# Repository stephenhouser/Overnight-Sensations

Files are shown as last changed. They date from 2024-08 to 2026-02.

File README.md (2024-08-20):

# Overnight Sensation Speakers

Overnight Sensations

This repository contains my build plans for [Paul Carmody](https://sites.google.com/site/undefinition/diy?authuser=0)'s **Overnight Sensations** speakers. It is intended to compliment Paul's designs, plans, and notes with manufacturable components. That is herein lie full CNC-able and PCB-producable components.

This currently includes details for the [original bookshelf speakers](https://sites.google.com/site/undefinition/bookshelf-speakers/diy-overnightsensations), the [floorstanding TMM's](https://sites.google.com/site/undefinition/floorstanding-speakers/overnightsensationtmm?authuser=0), and the [center speaker](https://sites.google.com/site/undefinition/home-theater-speakers/overnightsensationcenterchannelbipolewhatwhen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). I have future plans to include the [surround speakers](https://sites.google.com/site/undefinition/home-theater-speakers/overnightsensationcenterchannelbipolewhatwhen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).

This is a work in progress, bear with me as I build the speakers and add the components.

### A few notes on the designs

- Designed for 1/2" material. Using the 1/2" plans in all cases.
- Uses miter joints at the box corners, so can use already faced plywood.
- Uses painted MDF for the baffle. Could use faced plywood but the fillet on the outside edges would need to be removed.
- Does not use rabbet for back. Seems an overly complicated addition.

If you are using something else, it should be easily adapted.

## Bookshelf TM

No build files available.

I built these a few years ago and did not document things very well, save for a few photos and the build documents.

## Floorstanding TMM

TMM Glamor Shot

Includes:

- Cabinet Plans in FreeCAD
- Crossover PCB in KiCad with Gerbers for PCB manufacture
- 2"x3" port in FreeCAD for 3D printing

These are the most well developed plans as they are the most recent I've worked on.

NOTE: The version I have designed for uses the HiVi T20 tweeter and 1/2" thick wood for the cabinet. I've made some attempt at making the design general and adaptable, but you will likely have to tweak if you build the alternate version.

The cabinet design was reproduced from Paul's SketchUp screen capture into FreeCAD. The full FreeCAD files are in the [floorstanding[(floorstading)] directory. Here's a snapshot of the major dimensions. Perhaps enough to build from.

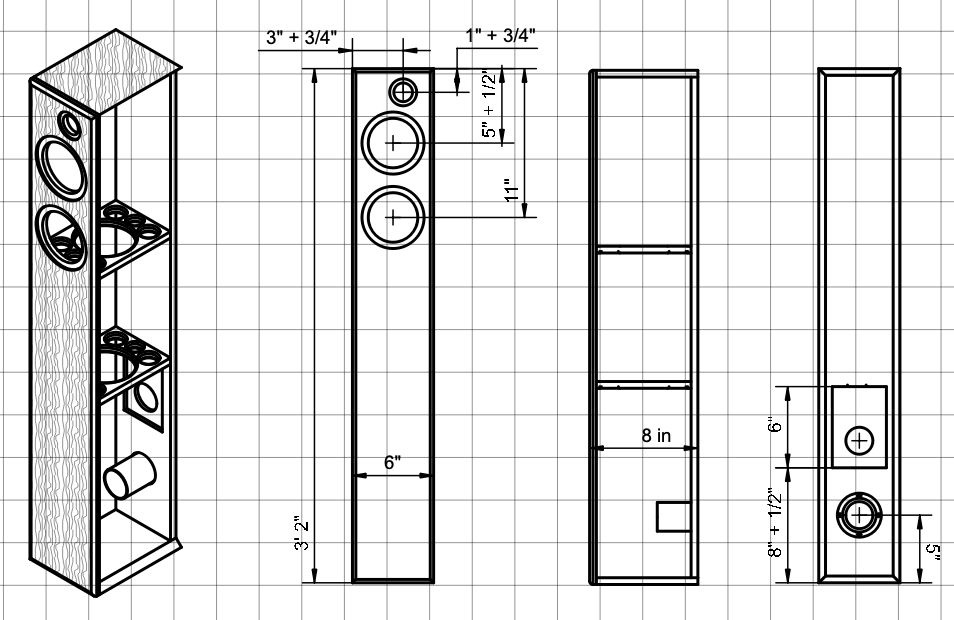
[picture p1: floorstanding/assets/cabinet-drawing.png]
Cabinet Drawing


My crossover PCB is for the HiVi T20 tweeter. You can use the same PCB, just substitute the different value components.

**NOTE**: I started working on alternate crossovers with thicker traces but stopped. See the notes below about **Power Handling**. I think the 3mm traces I have are "thick enough" for this configuration under normal use. It would be nice to have thicker traces (5-6mm), and 9.5mm spaced screw terminals. If I ever do make another PCB, I'll make those changes. Oh, I also forgot to put in additional holes for the wire ties on the 1.5 mH coil.

## Center MMTM

Cabinet Drawing

Next to be built!

## Surround

Yet to be built!

## Software Tools

I use the following software in the production of these. These are all open-source freely available products.

- [Inkscape](https://inkscape.org) for basic drawing and to generate SVG files for patterns.
- [KiCad](https://www.kicad.org) for schematic capture and PCB design.
- [FreeCAD](https://www.freecad.org) for cabinet design and CAM toolpath generation.
- [LibreOffice](https://www.libreoffice.org) for spreadsheets, bill of materials (BOM).

In the past I used the following software in parts of the process but am quickly moving away from them as I migrate to FreeCAD and other more open and interchangable software.

- [Carbide Create](https://carbide3d.com/carbidecreate/) / [Carbide Motion](https://carbide3d.com/carbidemotion/) for 2D CAD/CAM on Shapeoko 3
- [Autodesk Fusion 360](no link, autodesk keeps taking features away and I don't want to support that) for cabinet design and CAM toolpath generation

## Power Handling

To calculate what the power rating of the speaker is, and the appropriate trace width for the crossover boards.

- HiVi B4N is rated 25W RMS (50W max) at 8 Ohms, 60 - 4,000 Hz
- HiVi B3N is rated 10W RMS (30W max) at 8 Ohms, 80 - 12,000 Hz
- HiVi T20-8 is rated 15W RMS (no max specified) at 8 Ohms, 4,000 - 20,000 Hz

From some random source on the Internet:

    roughly 40-40-20 percentage for woofer, mid, tweeter

From [celestion](https://celestion.com/blog/power-handling-all-you-need-to-know/)

    As a rule of thumb, the cabinet power handling should be calculated as a multiple of the lowest rated speaker. For example in a 2×12 containing a 60-watt speaker and a 30-watt speaker, overall cabinet power handling is 2×30-watt = 60-watt. In a 4×12 containing 2×60-watt speakers and 2×30-watt speakers, overall cabinet power handling is 4×30-watt = 120-watt.

By this measure:

The TMM is either 25*.4+25*.4+14*.2 23W (43W max) or 3x15W = 45W (90W max) into an 8 Ohm speakers. With `I = E/R`, `23/8 = 2.875A` or `43/8 = 5.73A` max.

Using [Digikey Trace Size Calculator](https://www.digikey.com/en/resources/conversion-calculators/conversion-calculator-pcb-trace-width) and looking at "Required Trace Width" for "External Layers in Air":

- 2.7A, 22 degrees-C, 1 Oz weight, 4 inches, 20 degree rise gives **0.78 mm trace width**
- 5.73A max, 22 degrees-C, 1 Oz weight, 4 inches, 20 degree rise gives **2.19mm trace width**

I also calculated voltage drop and resistance of these traces, but not sure how to evaluate these in an objective way. Citations needed.

- 0.78mm trace width, 0.07 Ohms, 0.18V voltage drop, 0.49W power loss
- 2.19mm trace width, 0.02 Ohms, 0.13V voltage drop, 0.79W power loss

## NOTE: About The Files

There may be extraneous generated files in the directories, like generated GCode, Gerber files, and such. These are outputs from processes and may not be suited to your manufacturing equipment. You should regenerate these for your own equipment, don't use mine. I warned you.

The `Common-Crossover` directory is not used. This is a work-in-progress of designing a common crossover PCB that could work on all the Overnight Sensation speakers. It started when I thought my trace widths were not sufficient. **It is incomplete**.

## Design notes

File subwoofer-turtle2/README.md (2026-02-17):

# Turtle 2 Subwoofer

I always seem to have a super hard time finding this thread on the 
[Turtle 2 Subwoofer](https://techtalk.parts-express.com/forum/tech-talk-forum/40208-whole-buncha-sub-designs-for-the-rss210hf-4)

> The Turtle - A simple cube. For some reason, this is a popular shape for subs. I never understood why. It's pretty much impossible to use 3" PVC in this box, and a slot port would be too much extra work. So as a compromise, I think the 2" Precision Port kit should work. The port is downfiring because I was concerned about chuffing and because the flare is so large it won't fit on the back.

14"(wide) x 14"(tall) x 14"(deep)

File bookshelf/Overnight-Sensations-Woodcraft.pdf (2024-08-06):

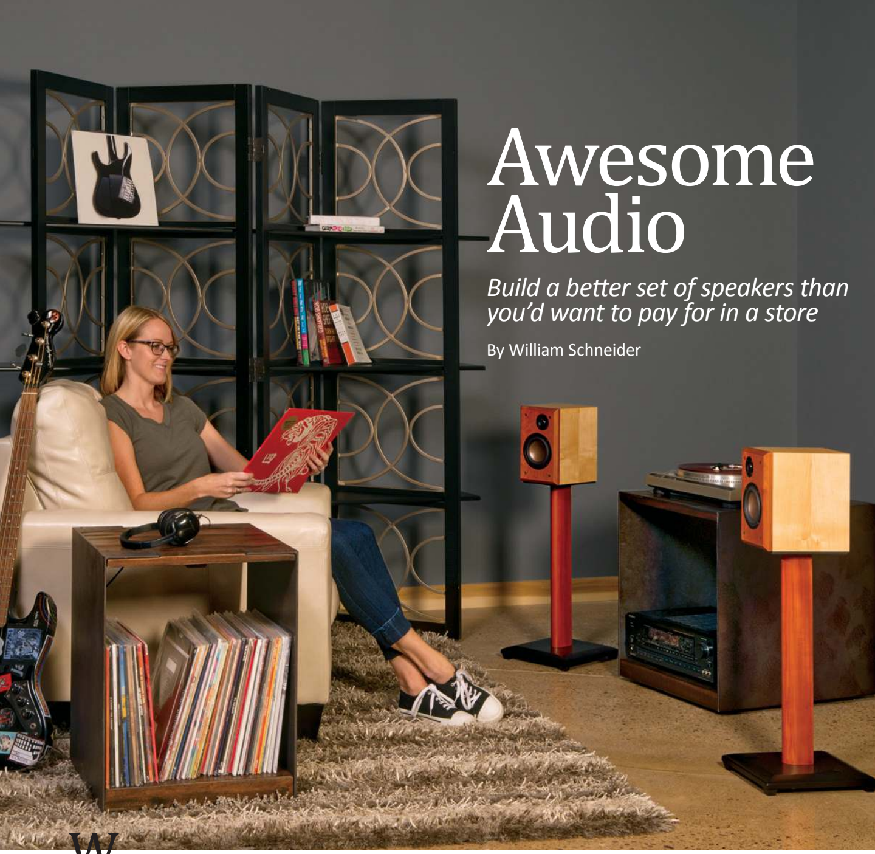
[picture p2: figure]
Awesome Audio; Build a better set of speakers than you’d want to pay for in a store; By William Schneider

Opening photo: Morehead Photography | Oct/Nov 2016 | woodcraftmagazine.com | 53

Who says that you can’t

build a set of loudspeakers that can sound better than those you can buy? You’ll discover that most commercial loudspeaker manufacturers take steps to lower the cost of manufacturing and shipping their products.
Two places where corners are cut are cabinet quality and in the electronic assemblies inside. These impact sound quality. Working in your own shop you can make stout cabinets that won’t resonate when the piano hits middle C. Inside, a well-designed crossover will blend low through high tones smoothly. While you may be comfortable tackling the cabinets, you might feel uneasy about the electrical tasks. But don’t worry. With kits like the Overnight Sensations from Meniscus Audio (see Buyer’s

# Guide, p. 64), the difficult electrical

design work is already done. All you have to do is assemble the parts per instructions. The kit featured here contains everything you need except for the wood. Even though the kit requires soldering electrical components together, supplied stick-on templates show where
each item goes. If you can’t solder, already assembled
crossovers are available.

54 | woodcraftmagazine.com | Oct/Nov 2016

# Speaker anatomy: Basic box, beautiful baffle, balanced electronics

Audio expertise isn’t required to

# build first-class speakers, thanks

to the balanced components that come in the kit shown below. (But the “Audio 101” vocabulary on the facing page will give you some useful basic knowledge.) These bookshelf-size speakers are sized to house the components, but you can apply the same construction techniques to build larger speakers as well. MDF makes excellent speaker cabinet material because its dense, uniform composition helps minimize unwanted vibration. Because MDF has poor screw-holding capability, I glued plywood corner brackets to the box interior to hold the four

# baffle installation screws. Invest in

some nice-looking veneer to cover the MDF, and select some attractive hardwood to make your baffles.

# Construction sequence

- Mount electronics on crossover board.

## - Make the baffle and build the MDF

box, then veneer the box.
- Apply finish to baffle and box.
- Install speaker components.
- Screw baffle to box to complete speaker cabinet.

Just add wood. At $130, the Overnight

### Sensations speaker kit is a good choice for

someone wanting to try speaker building.

The kit contains everything you need for two speakers: electronic components, damping material, crossover boards with templates, screws—and candy. You supply the wood and adhesive-backed foam tape (weather stripping).

TOP

3

⁄4 × 4¹

⁄2 × 8¹

⁄4"

1

⁄8" thick × ¹

⁄4" wide
vinyl foam tape

TWEETER

### MID-WOOFER

### HARDWOOD BAFFLE

3

⁄4 × 6 × 9¹

⁄2"

### Note: Meniscus specifies ¹

⁄2"-thick
material for the speaker cabinet.
I adjusted cabinet dimensions so that

3

⁄4"-thick stock can be used.

Port

Crossover
boards

Coil Electronics and screws

Terminal cup

### Damping

material

Driver gasket | Mid-woofer | Tweeter | Crossover templates

# Speaker anatomy: Basic box, beautiful baffle, balanced electronics

# Audio 101

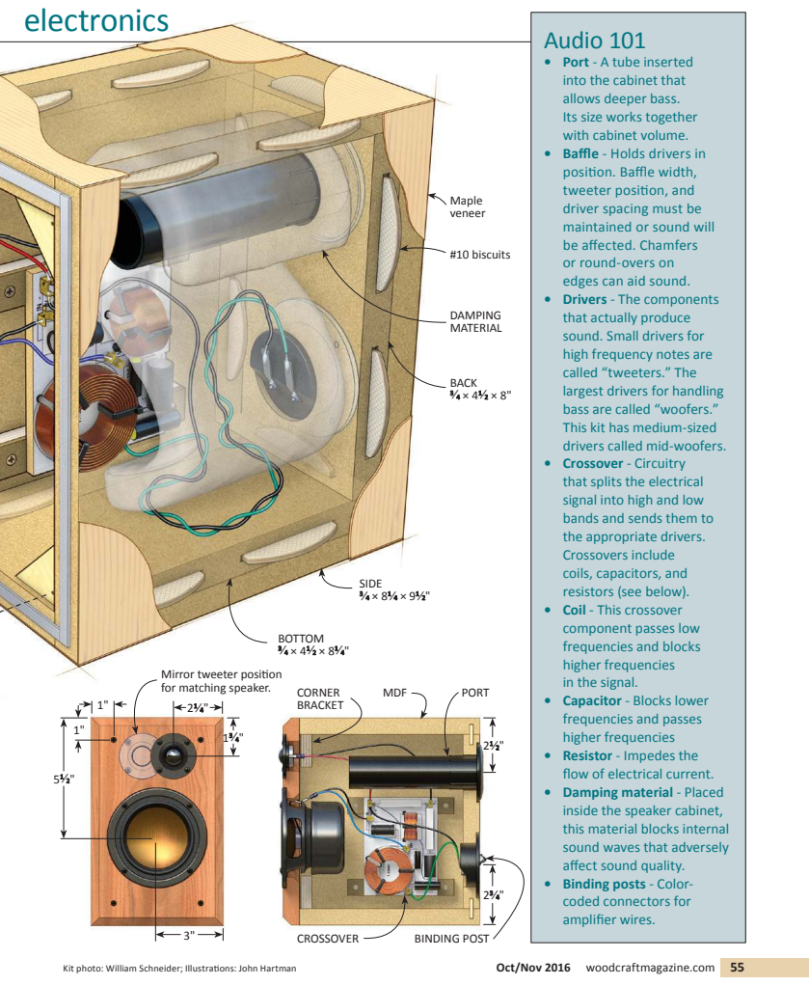
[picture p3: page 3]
Kit photo: William Schneider; Illustrations: John Hartman; Oct/Nov 2016; woodcraftmagazine.com; BACK; BOTTOM; PORT; BINDING POST; CORNER BRACKET; Mirror tweeter position for matching speaker.; DAMPING MATERIAL; #10 biscuits; SIDE; Maple veneer; MDF; CROSSOVER

• Port - A tube inserted
into the cabinet that
allows deeper bass.
Its size works together
with cabinet volume.
• Baffle - Holds drivers in
position. Baffle width,
tweeter position, and
driver spacing must be
maintained or sound will
be affected. Chamfers
or round-overs on
edges can aid sound.
• Drivers - The components
that actually produce
sound. Small drivers for
high frequency notes are
called “tweeters.” The
largest drivers for handling
bass are called “woofers.”
This kit has medium-sized
drivers called mid-woofers.
• Crossover - Circuitry
that splits the electrical
signal into high and low
bands and sends them to
the appropriate drivers.
Crossovers include
coils, capacitors, and
resistors (see below).
• Coil - This crossover
component passes low
frequencies and blocks
higher frequencies
in the signal.
• Capacitor - Blocks lower
frequencies and passes
• Resistor - Impedes the
flow of electrical current.
• Damping material - Placed
inside the speaker cabinet,
this material blocks internal
sound waves that adversely
affect sound quality.
• Binding posts - Color-
coded connectors for
amplifier wires.

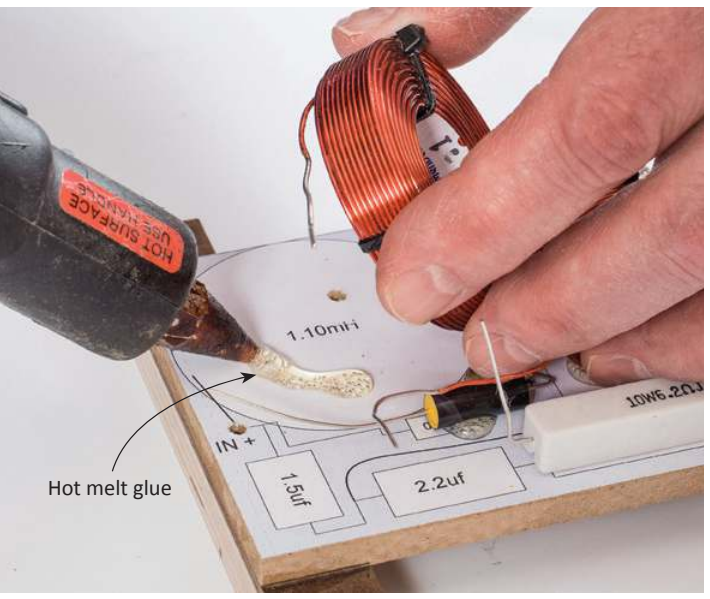
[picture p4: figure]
Hot melt glue

# Soldering 101

To solder electrical components, you’ll need a soldering iron and electrical solder. Pencil irons begin at $15, but I use a $50 Weller

## adjustable heat soldering stati on. Use 60/40

rosin core, 0.031"-diameter solder.

## To solder, touch the hot ti p to the joint for a few seconds, and feed solder between ti p and joint unti l it melts and fl ows into the joint. Move solder

to coat other parts in the joint. I spend about 5 to 8 seconds per joint. A good joint should be shiny like chrome, not grainy. Occasionally wipe
the soldering iron ti p clean on a damp sponge.
Once you learn to solder, projects

## like fl oor lamps, table lamps, and power

tool repair all become possible.

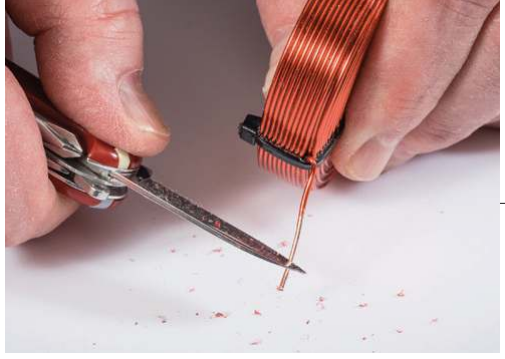
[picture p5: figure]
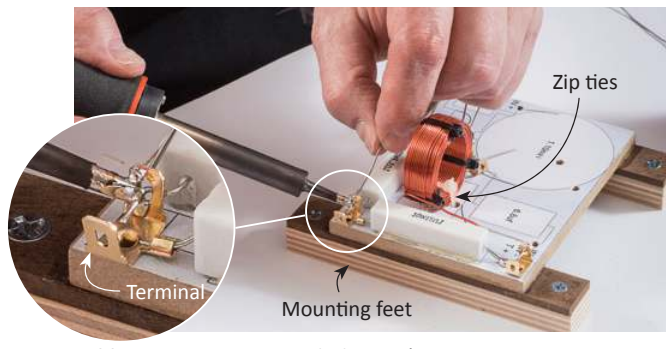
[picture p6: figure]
Zip ti es; Mounti ng feet; Terminal

56 | woodcraftmagazine.com | Oct/Nov 2016

# Mount & wire the electronics

Some soldering is required to connect the speaker’s electronic components. If you feel uncomfortable soldering, you can order pre-assembled crossovers from Meniscus for an extra charge. Mounting components and soldering

# connections are simplified, thanks to

included templates you can glue to crossover boards, as shown in these photos.
Plan how to mount the crossovers inside the speaker cabinet. I cut ³⁄4 × 5" strips of

hardboard and plywood to use as feet for the crossovers. The plywood feet are glued to a cabinet wall, but the hardboard strips (which are glued to the crossover board and screwed to the feet) can be removed.

### Follow the template. Glue the kit’s template to the

crossover board, then use hot melt glue to adhere the

### parts. Add zip ti es to secure heavy coils. Fit the leads

into their terminal openings before soldering.

Skin the coat. Coil wire is coated with enamel that

### interferes with soldering. Use a knife to scrape the

coati ng from wire that needs to be soldered.

### Solder a connecti on. Touch the iron’s ti p to a connecti on for a couple of seconds. Without lift ing the ti p, feed solder between ti p and connecti on, melti ng the solder. Maintain heat for a second aft er suffi cient solder has fl owed, then pull the

iron’s ti p away. Allow several seconds for solder to solidify.

Soldering
iron

Solder

Home-made

### ti p holder

Soldering

### stati on

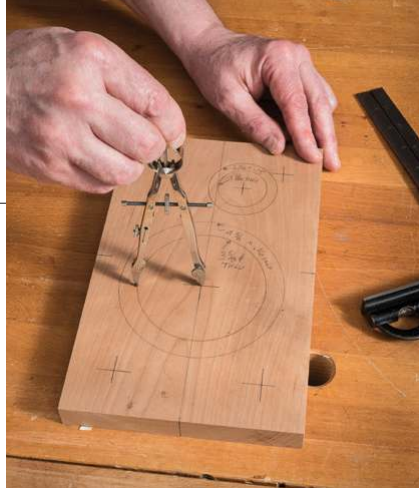
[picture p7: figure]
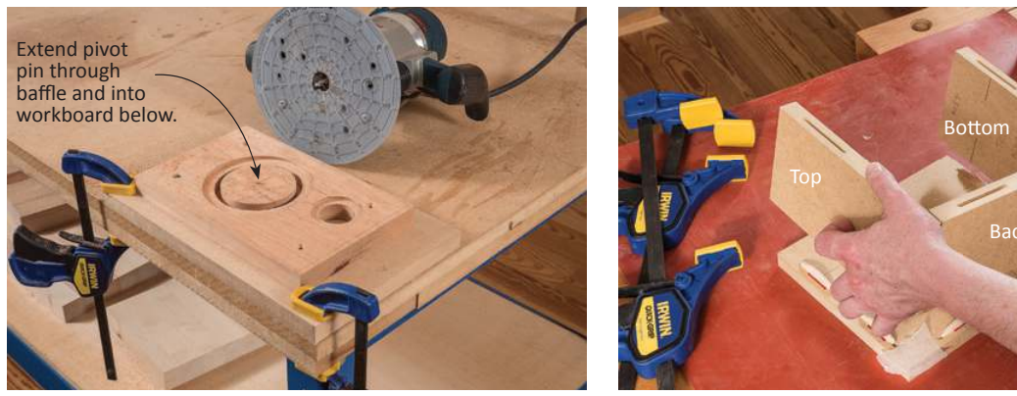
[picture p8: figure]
Extend pivot pin through baffl e and into; workboard below.; Bott om; Top
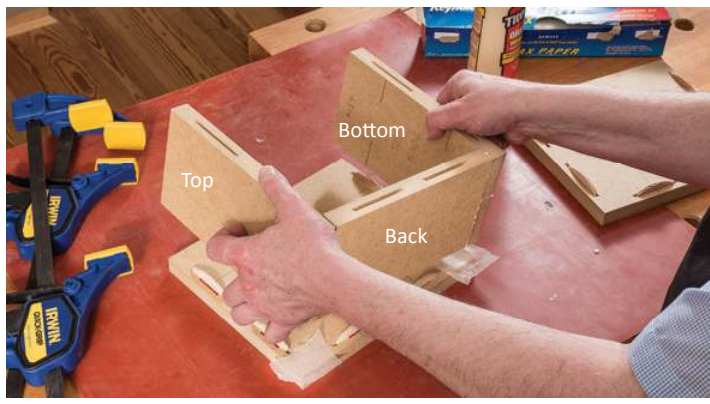
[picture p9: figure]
Back
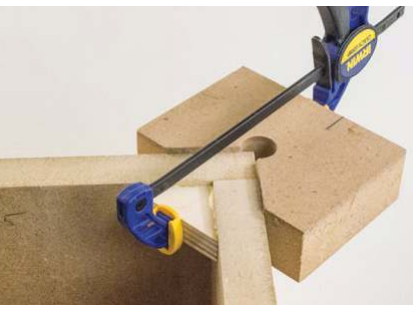
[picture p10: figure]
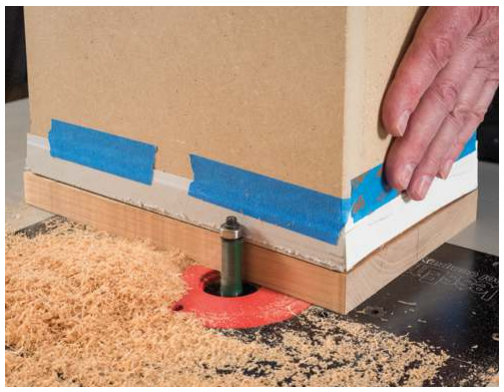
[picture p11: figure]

Photos: Larry Hamel-Lambert, except soldering stati on and corner bracket photos: William Schneider | Oct/Nov 2016 | woodcraftmagazine.com | 57

The baffl e is tricky; the box is easy.

# Assemble, then trim

# Speaker cabinets require good-fitting parts to minimize unwanted

vibration, so cut parts and rout holes precisely. I start with the

# baffle, cutting it about 3⁄16" over its finished size. Each baffle requires

a large, round, rabbeted hole for the mid-woofer and a smaller

# rabbeted hole for the tweeter. I rout the holes in the baffle and the

back with a Jasper circle-cutting jig attached to the base of my router and a ¹⁄4" straight bit. If you haven’t routed circles with a Jasper jig

before, you might want to make some practice cuts on scrap stock.

# Rout the rabbeted section of each baffle hole first, then rout

the hole by making a series of successively deeper cuts.

# Put the baffle aside after holes are routed, and turn to making the MDF

box. I assemble the box with biscuit joints and glue. My biscuit joiner workstation (p. 50) helps me cut slots quickly. When the box is together, temporarily attach the baffle so it can be flush-cut with a flush-trim bit.

### Lay out each baffl e. Locate each hole carefully. Use the compass to

mark the opening and the rabbet
to hold each driver’s fl ange.

### Rout holes for drivers. Att ached to the base of your router, a Jasper jig is ideal for speaker constructi on. It

enables you to rout circular recesses and holes from 1" to 7¹

⁄2" in diameter in ¹

### ⁄16" increments. Use a ¹

⁄4"

spiral upcut bit, and take passes about ¹

⁄8" deep.

Glue up the box in stages. Cut slots for #10 biscuits in box sides,

### back, top, and bott om. Then glue the back, top, and bott om

together. Place a side on the workbench as I’m doing here, to use

### as a positi oning guide before clamping up this subassembly. Wax

paper keeps your glue-up from sti cking to the positi oning guide.

### Flush-trim the baffl e. Doing this

before veneering
the box prevents
router bearing
tracks in the
veneer. Tape some
cardboard (about
0.030" thick) to
approximate the
veneer thickness.

### Install corner blocks. Cut corner blocks

to hold the screws for the baffl e.

Mount them about ¹

⁄16" below fl ush.

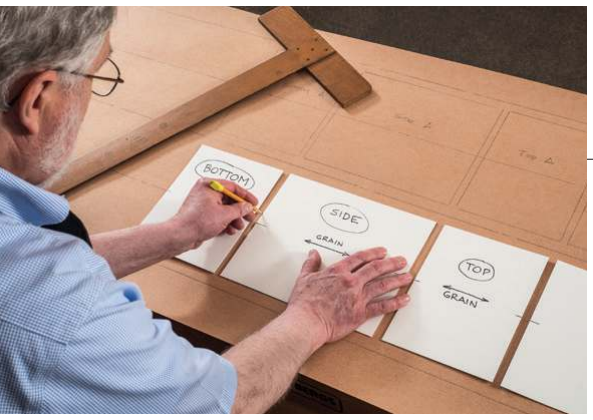
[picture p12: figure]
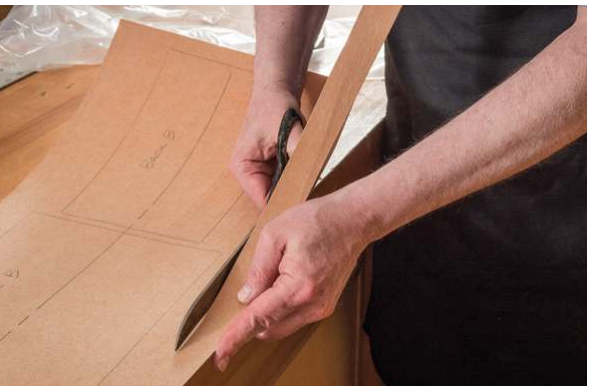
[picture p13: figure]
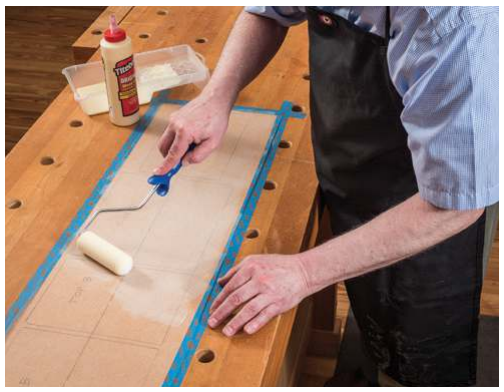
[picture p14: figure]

58 | woodcraftmagazine.com | Oct/Nov 2016

# Iron on some veneer for an easy appearance upgrade

While MDF takes paint well after a couple rounds of shellac and sanding, it’s even easier to veneer. The iron-on method, using paper-backed veneers and an ordinary clothes iron, is straightforward and simple. Coat both the cabinet and the veneer with Titebond Original, let the glue dry, and iron on the veneer. Once dried, the glue will still reactivate for up to seven days. The veneer doesn’t stick until you apply
heat, so it’s fairly easy to position each piece precisely. Veneer the back first, then the bottom,

sides, and top. After ironing on a piece of

# veneer, trim the overhanging edges flush with

a flush-trim bit. Then move to the next side.

Once all sides are complete, use the wood

# finish of your choice. I wiped on several coats

of General Finishes Arm-R-Seal satin.

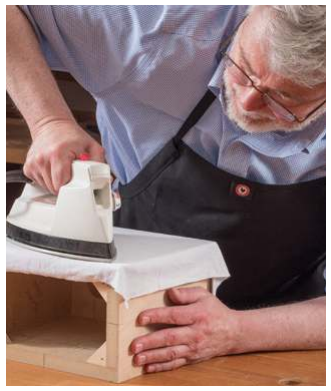
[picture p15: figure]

### Cut it out. Using scissors or a knife, cut groups of tracings

from the roll, leaving a little extra margin all around.

### Map out your veneer. Make cardboard patterns

1

### ⁄2" oversize and position them on the veneer as

shown. Allow at least ¹

⁄4" between the pieces.

### Spread glue on veneer and cabinet. Tape the

edges of veneer to a table, then use a sponge
paint roller to apply glue. Let the glue dry.

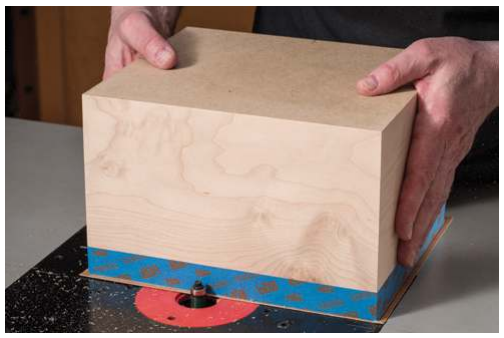
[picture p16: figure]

### Flush-trim veneer overhang. Use a flush-trim bit in a router

or router table to quickly remove the excess veneer from the edges. Tape reduces bearing tracks on already-veneered sides.

### Iron on the veneer. Position

the veneer as
desired. Place

### cotton cloth

(t-shirt material
works well)

### over it. Using an

ordinary clothes

### iron on the cotton setting, press firmly and work

slowly to adhere
the veneer.

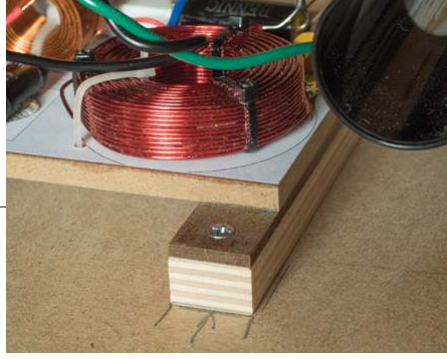
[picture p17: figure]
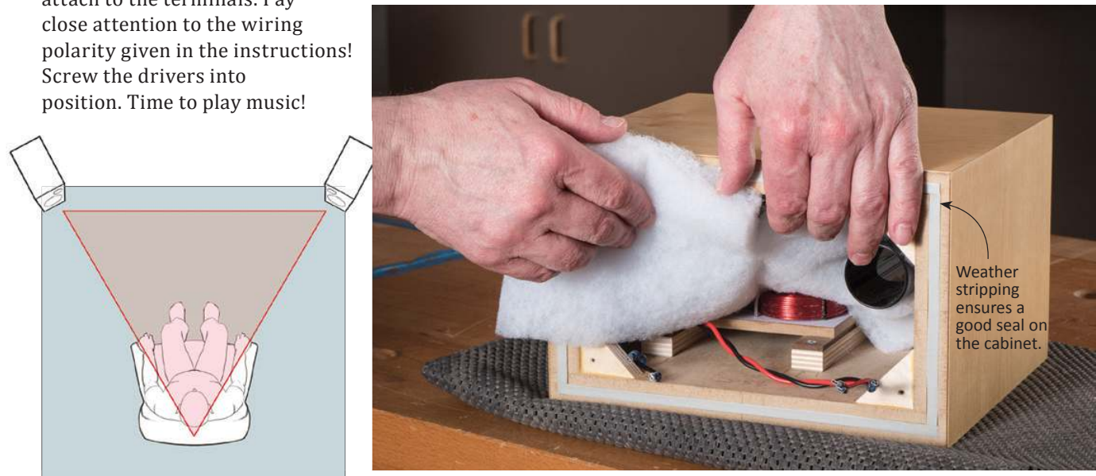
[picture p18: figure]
close attention to the wiring polarity given in the instructions! Screw the drivers into position. Time to play music!; Weather stripping ensures a good seal on the cabinet.
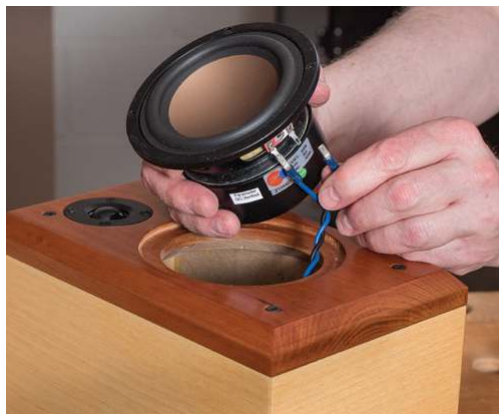
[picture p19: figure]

Oct/Nov 2016 | woodcraftmagazine.com | 59

# Sweet Spot Setup

Viewed from above, speakers and the listener should form an equilateral triangle. Most speakers sound best placed at least a yard from large surfaces like walls or large TVs. The listening seat should also be in the open. While real-world compromises are

## oft en involved, you owe it

to yourself to listen to these speakers at least once in the

## ideal confi gurati on before

tucking them against the wall.

Mount assembled crossover boards.

### Find a locati on on a side wall where

nothing will interfere with the crossover.

### Spread wood glue on the bott om of the

crossover feet, and press them into place for a minute or two. Set aside to dry.

Att ach leads to drivers.

Each driver has a “+”
and a “-” terminal (plus

### is someti mes coded

red). It’s important to
use correct polarity

### per kit instructi ons. To att ach wires, either use

the included push-on
connectors or solder
the wires directly to
the driver terminals. Be
sure the driver gaskets

### are in positi on before

att aching leads.

Insert damping material. Cut to size and insert, but be careful not to block the port.

Mount the crossover board,

# install the baffl e, then Rock Out

# After applying a finish, it’s time to install the crossovers

and ports, mount the wires, and attach the drivers. First, mark and drill pilot holes for all mounting screws. Glue the crossover assemblies onto an interior side wall. Once secured, run the wires for the binding posts out the back opening,
and use the push-on connectors to connect the crossovers to the binding posts. Using the kit screws, attach the binding post to the cabinet. Press the port into place, and then secure with glue. If the port flanges are oversize, file them to fit.

# Insert the damping material, and screw the baffle into

position. Run the wires through the driver openings, and attach to the terminals. Pay

Woodcraft Magazine wants to help inspire YOU with projects,

# tips, and techniques with a special offer for Woodcraft customers!

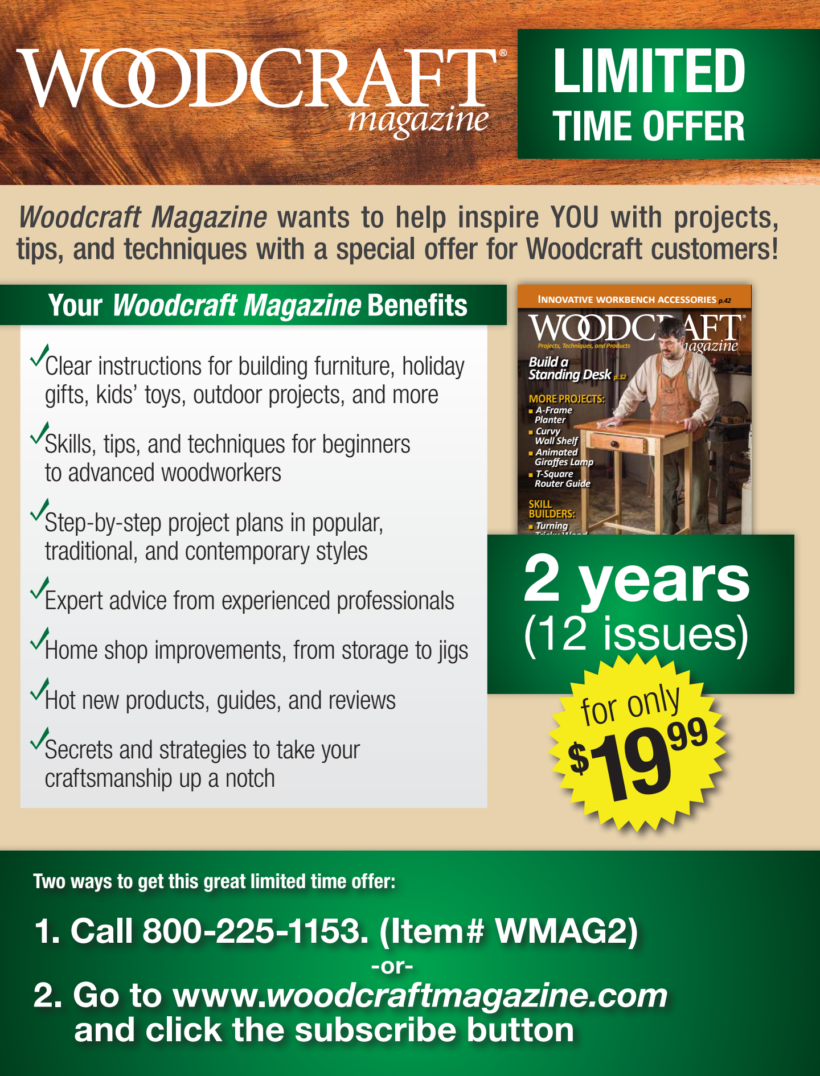
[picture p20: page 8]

2 | woodcraftmagazine.com | April/May 2016

# 1. Call 800-225-1153. (Item# WMAG2)

-or-

# 2. Go to www.woodcraftmagazine.com and click the subscribe button

## Two ways to get this great limited time offer:

Projects, Techniques, and Products

n A-Frame
Planter
n Curvy
Wall Shelf
n Animated
Giraffes Lamp
n T-Square
Router Guide

MORE PROJECTS:

Innovative workbench accessories p.42

Build a
Standing Desk p.32

n Turning
Tricky Wood
n Mastering
Half-Blind
Dovetails

SKILL
BUILDERS:

# LIMITED

# TIME OFFER

# 2 years

# (12 issues)

# Clear instructions for building furniture, holiday gifts, kids’ toys, outdoor projects, and more

# Skills, tips, and techniques for beginners to advanced woodworkers

Step-by-step project plans in popular,

# traditional, and contemporary styles

# Expert advice from experienced professionals

# Home shop improvements, from storage to jigs

# Hot new products, guides, and reviews

# Secrets and strategies to take your craftsmanship up a notch

# Your Woodcraft Magazine Benefits

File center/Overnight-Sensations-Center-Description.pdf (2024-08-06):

Overnight Sensations Center Channel

First, the center channel is meant to be very thin to compliment a modern flat screen home theater setup. It uses four of the HiVi B3N and the HiVi T20 tweeter. I am exceptionally pleased with how this speaker sounds. I even left it on mono and listened to music through it for a few days just 'cause it could do it. The cabinet is pretty simple, and calls for 1/2" stock

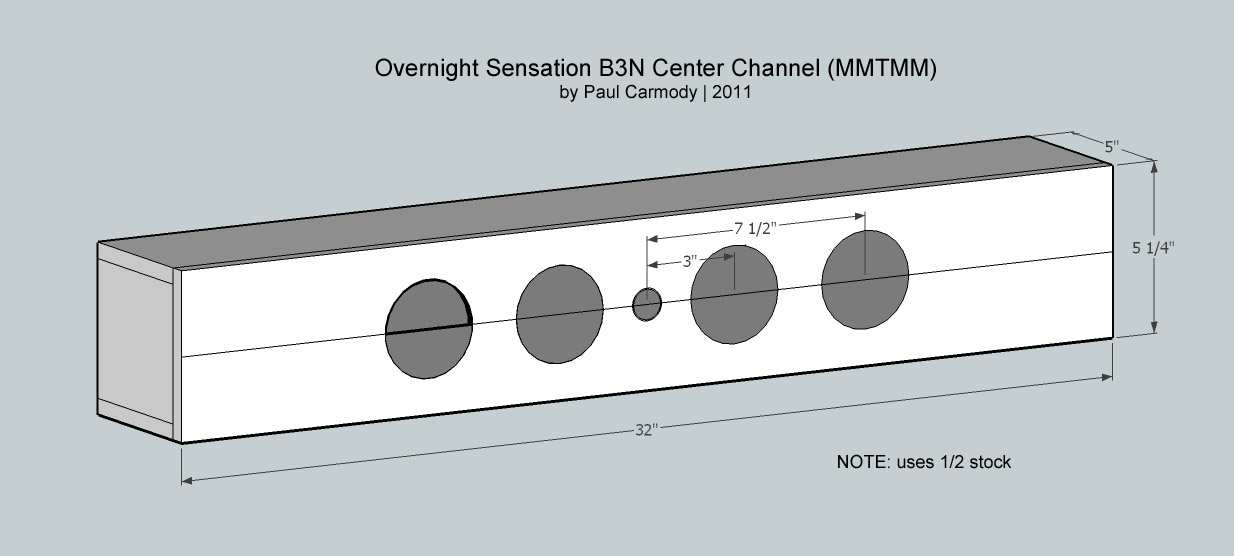
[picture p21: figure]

The crossover for the MMTMM is a 2.5-way, which means that the outside woofers only play "bass duty," while the inside woofers play both mids and bass. The crossover is relatively simple. For inductor L3, you can use an iron-core and it should be no
problem.

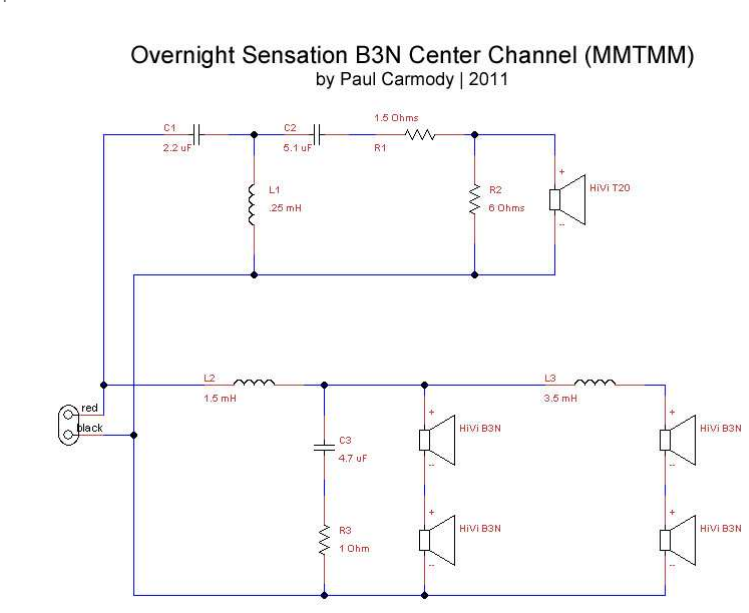
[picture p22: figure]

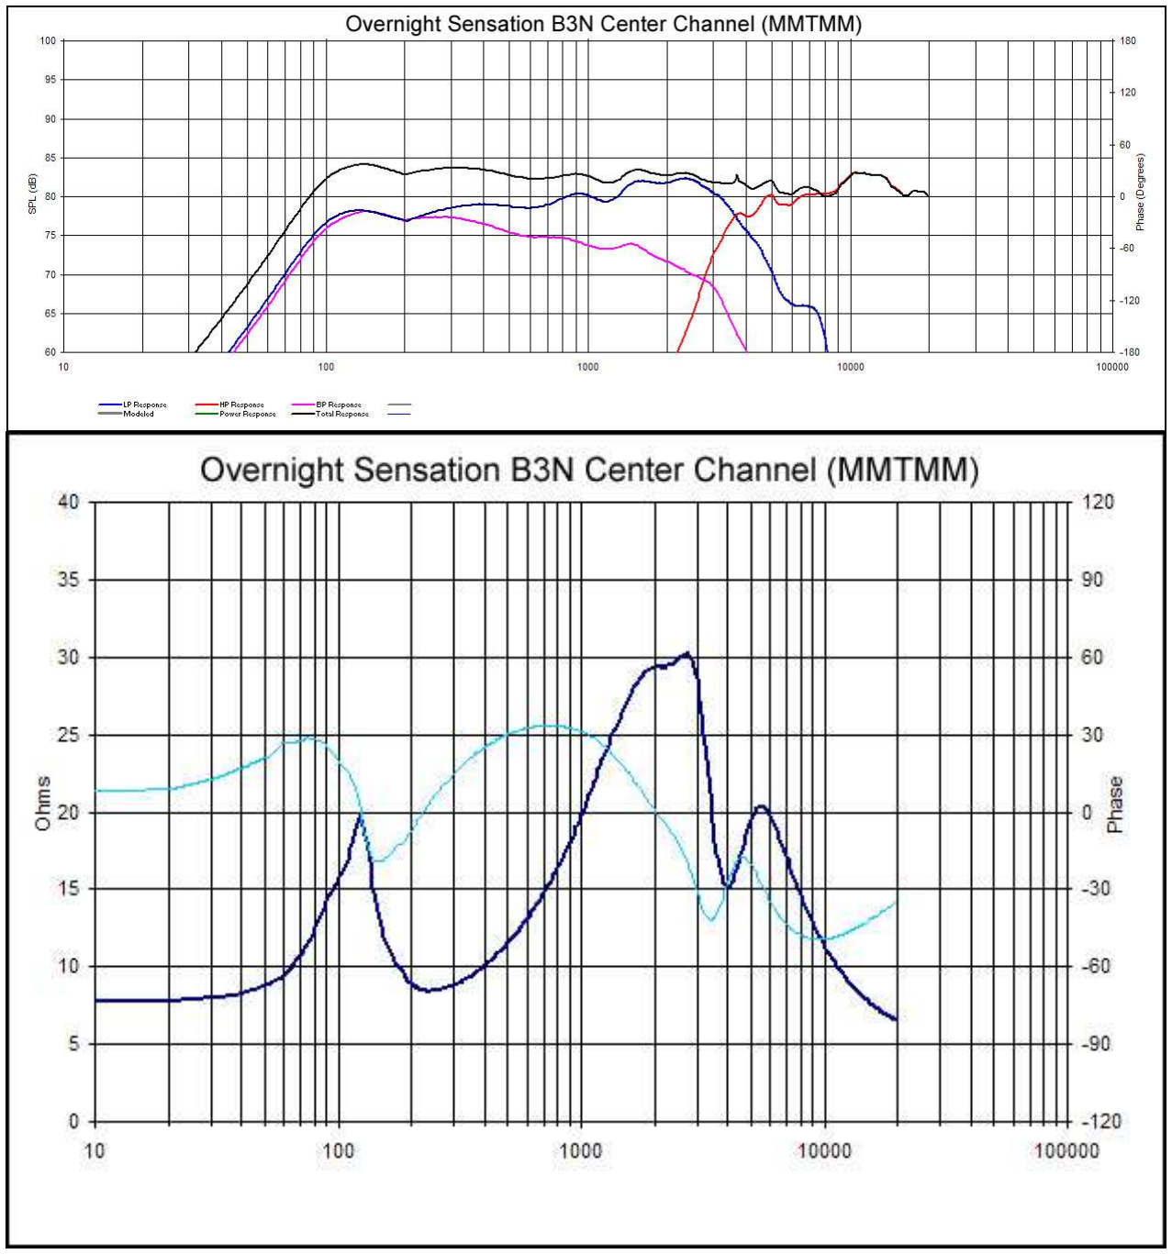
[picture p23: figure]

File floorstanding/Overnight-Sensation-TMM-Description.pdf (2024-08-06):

# Overnight Sensation TMM Tower

What? You mean I'm not done with the Overnight Sensations?

OK, so here's the story. Back when I designed the Overnight Sensation MTM, I knew some folks were going to want to make towers out of them--and there are plenty of excellent examples out there. However, my mind would always play around with the cabinet shape, wondering what else was possible. For some reason TMM towers are almost always more pleasing to my eyes than MTM towers; maybe they create less visual impact in the room, maybe they look less like they might tip over, maybe I can just sense the Spouse Approval Factor.

TMM are certainly no panacea though, and in my opinion are much harder to get right in the crossover. However, I don't mind the challenge once in a while, and I have always been curious what kind

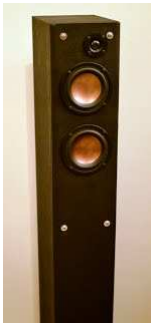
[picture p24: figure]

of deep bass I could get out of the B4N if they had a lot more cabinet volume to play into. So I decided that the only way I could sleep at night is if I finally just tried this design for myself. And I'm so glad I did. What a fun way to round up this series!

I wanted to keep the same general layout and dimensions as the original Overnight Sensations and OSMTM so that a family resemblance would be instantly apparent if these were placed in the same room as the originals. The Width is still 6", and the depth still relatively shallow. The nice, tall height gives us something we've never gotten to play with on the B4N: internal volume. Note: this is not a Transmission Line; it's just a simple, vented enclosure. I just drew up a shape I liked and designed around that. If someone wants to design a TL enclosure for this, be my guest

The internal volume is approximately 21 Liters, and there are 2-3 "windowpane" braces here and there. The vent is 2" diameter, and 3" long. This tunes the speaker to 50 Hz, and should give an F3 around 39 Hz. The vent is about 5" up from the bottom of the cabinet, and can be placed on the front or the back, depending on which you like the look of. The cabinet can be built with either .5" or .75" stock. I used a medium-light fill of polyfil in the top 2/3 of the cabinet.

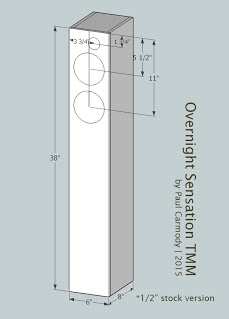
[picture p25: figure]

## Crossover Design


As might be expected, the crossover to the Overnight Sensation TMM is a 2.5-way, which means that it's basically a 2-way, but with an extra large inductor before the 2nd woofer to push its FR lower so it doesn't interfere with the tweeter. (eg: it just plays the low notes) The actual topology of this design actually closely mimics that of the original Overnight Sensations. It still uses a 2nd order with a "tank/elliptic" filter on the woofer, and a 3rd order with an L-pad on the tweeter.

Please note that there are two versions of the crossover. One uses the HiVi T20 tweeter, and the other uses the Dayton ND20FA-6. The sonic difference between the two is negligible; I offer both tweeter choices because I know that certain tweeters are only available in certain areas.



The impedance load of this design would probably be considered 4 Ohms nominal, however it just barely dips down there, and on the whole should be pretty benign for most solid state amps and home theater receivers. It's no worse than the OSMTM.

The good news is that since there is so much internal cabinet space, you can lay out the crossover pretty much however you want. Hell, you could even just lay out each filter exactly how it is on paper, if you are uncomfortable with Nodal Analysis.

## Listening Impressions

Everyone who's heard the original Overnight Sensations always thought to themselves, "Well, the bass is pretty good, especially for a speaker this small." So what happens when that same speaker isn't quite so small anymore? What kind of bass you think you could get? Yeah, the bass is pretty sweet on this. The F3 is around 39 Hz, but I voiced it with a just a hint of extra boom in the low bass because it kind of kept with the same sound as the rest of the Overnight Sensations family. You will be pleasantly surprised when a synth bass line comes in and you feel it. Personally, I wouldn't feel the need to use a sub with these, unless I was watching a lot of action movies. The mids and treble are right in-line with the rest of the Overnight Sensation family.

I only regret not putting this design together sooner, because over the years I've seen people wish to build something from the Overnight Sensation series, but wanted something floor standing, or with just some more bass to fill a medium-sized room. For everyday listening in a small space on a budget, I think this thing is a home run.

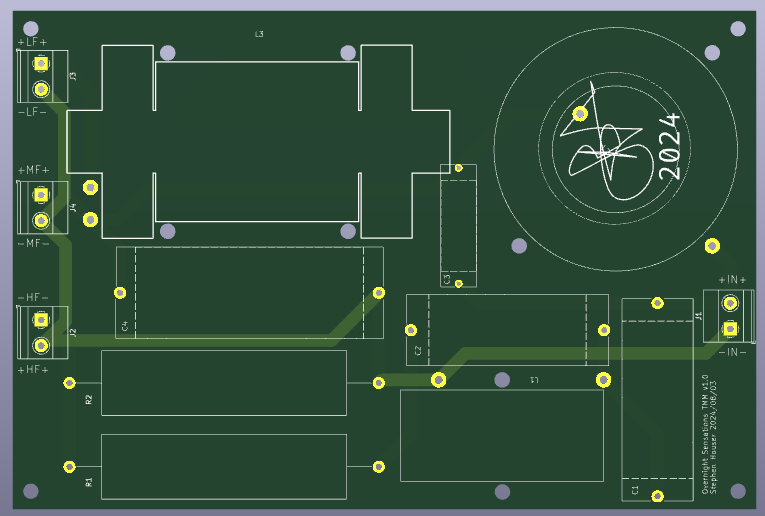
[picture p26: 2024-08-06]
floorstanding/assets/crossover-pcb-top.png

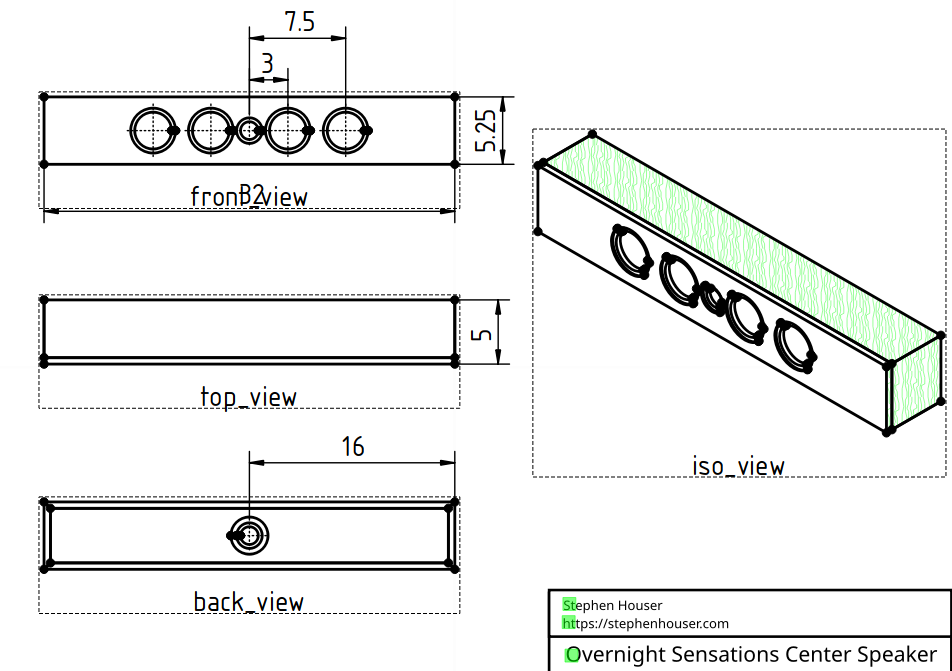
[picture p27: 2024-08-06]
center/assets/cabinet-drawing.png

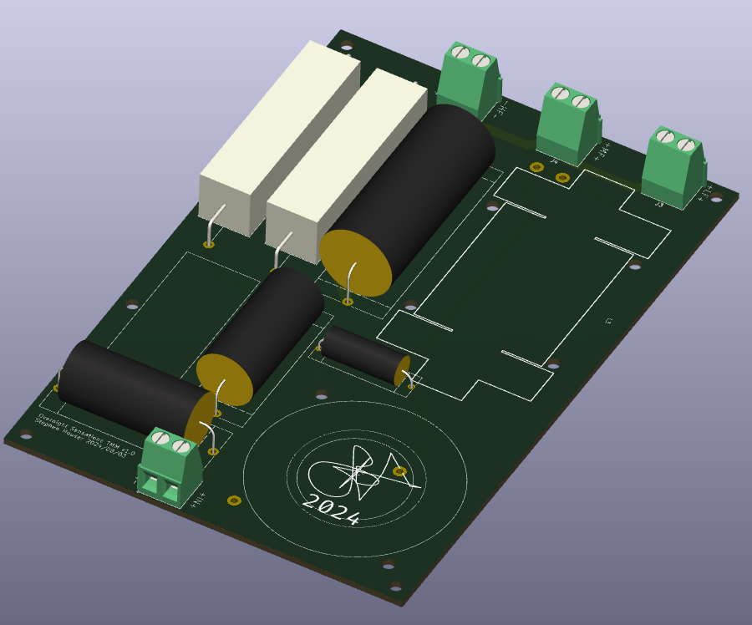
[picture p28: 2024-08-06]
floorstanding/assets/crossover-pcb-iso.png

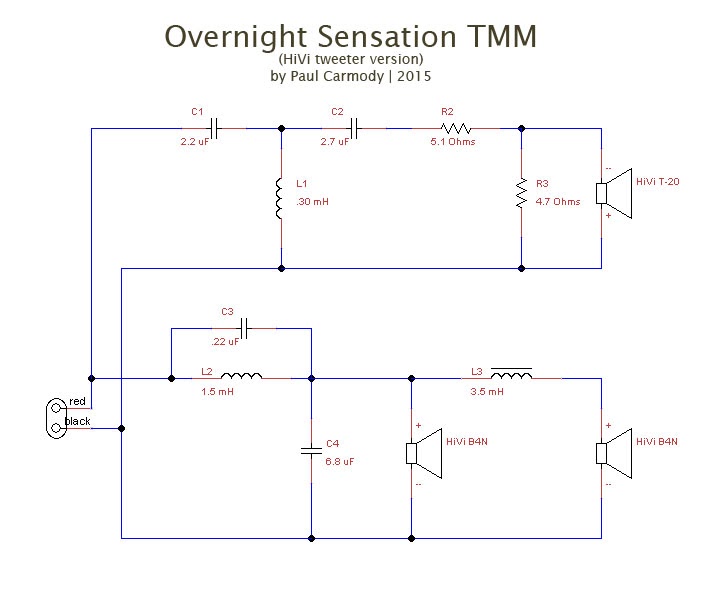
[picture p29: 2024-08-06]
floorstanding/Overnight-Sensation-TMM-Crossover.jpg

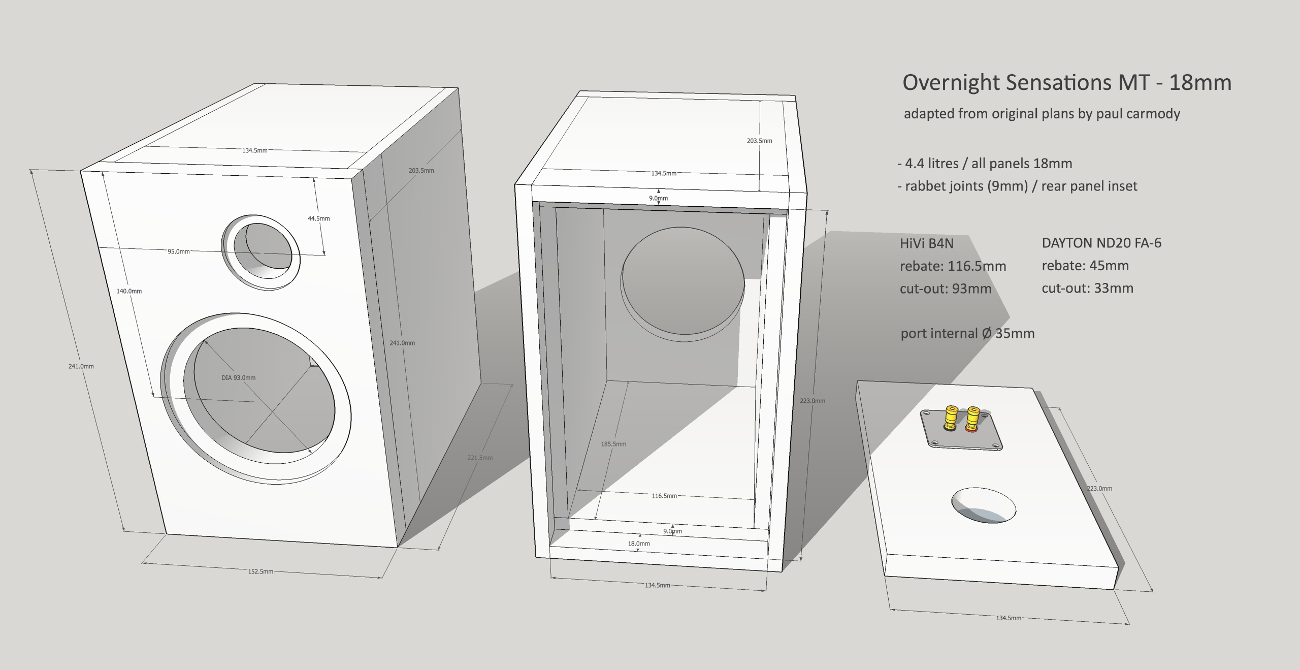
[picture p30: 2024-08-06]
bookshelf/Overnight-Sensations-Cabinet.jpg

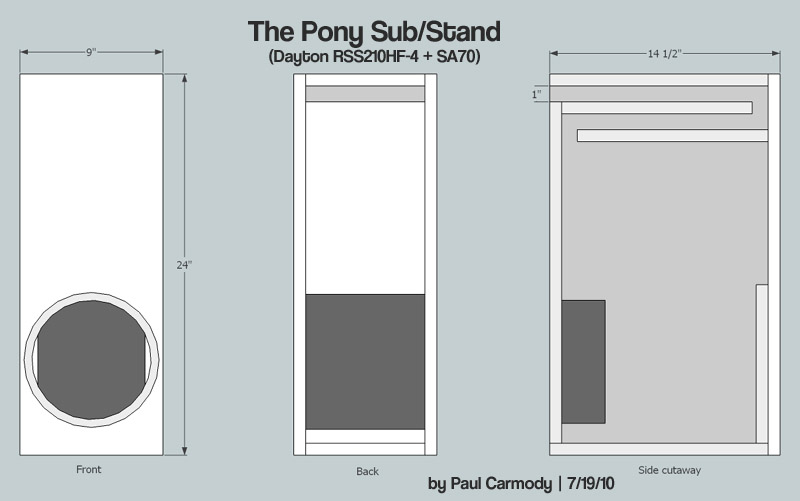
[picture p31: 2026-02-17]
The Pony Subwoofer/Pony diagram.jpg

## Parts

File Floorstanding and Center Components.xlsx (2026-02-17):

Overnight Sensations
 |  |  |  | ordered | received
Center | 1 | 2.2 | uF | x | 1
 | 1 | 5.1 | uF | x | 1
 | 1 | 4.7 | uF | x | 1
 | 1 | 1.5 | Ohms | x | 1
 | 1 | 6 | Ohms | x | 1
 | 1 | 1 | Ohms | x | 1
 | 1 | 0.25 | mH | x | 1
 | 1 | 1.5 | mH | x | 1
 | 1 | 3.5 | mH | x | 1
Floorstanding | 2 | 2.2 | uF | x | 2
 | 2 | 2.7 | uF | x | 2
 | 2 | 0.22 | uF | x | 2
 | 2 | 6.8 | uF | x | 2
 | 2 | 5.1 | Ohms | x | 2
 | 2 | 4.7 | Ohms | x | 2
 | 2 | 0.3 | mH | x | 2
 | 2 | 1.5 | mH | x | 2
 | 2 | 3.5 | mH | x | 2
Bookshelf

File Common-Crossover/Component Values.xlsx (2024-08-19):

Overnight Sensations Crossover Component Values
 | Bookshelf |  |  | Floorstanding |  |  | Center |  |  | Bipole
Component | TM | Length | Diameter | TMM | Length | Diameter | MMTMM | Length | Diameter | Surround | Length | Diameter
C1 | 1.50 | 31.00 | 11.00 | 2.20 | 31.00 | 13.00 | 2.20 | 31.00 | 13.00 | 1.50 | 31.00 | 11.00
C2 | 2.20 | 31.00 | 13.00 | 2.70 | 31.00 | 14.00 | 5.10 | 31.00 | 21.00 | 2.20 | 31.00 | 13.00
C3 | 0.22 | 18.00 | 7.00 | 0.22 | 18.00 | 7.00 | --- |  |  | 0.22 | 18.00 | 7.00
C4 | 6.80 | 48.00 | 18.00 | 6.80 | 48.00 | 18.00 | 4.70 | 31.00 | 19.00 | 10.00 | 48.00 | 22.00
R1 | 6.00 | 48.00 | 10.00 | 5.10 | 48.00 | 10.00 | 1.50 | 48.00 | 10.00 | 6.00 | 48.00 | 10.00
R2 | 10.00 | 48.00 | 10.00 | 4.70 | 48.00 | 10.00 | 6.00 | 48.00 | 10.00 | ---
R3 | 0.00 |  |  | 0.00 |  |  | 1.00 | 48.00 | 10.00 | 0.00
L1 | 0.35 |  |  | 0.30 |  |  | 0.26 |  |  | 0.35
L2 | 1.10 |  |  | 1.50 |  |  | 1.50 |  |  | 0.90
L3 | --- |  |  | 3.50 |  |  | 3.50 |  |  | ---
J2 | HF |  |  | HF |  |  | HF- |  |  | HF1
J3 | --- |  |  | --- |  |  | --- |  |  | HF2
J4 | MF |  |  | MF |  |  | MF1 |  |  | MF1
J5 | 0.00 |  |  | 0.00 |  |  | MF2 |  |  | 0.00
J6 | --- |  |  | LF |  |  | LF1 |  |  | MF2
J7 | --- |  |  | 0.00 |  |  | LF2 |  |  | 0.00

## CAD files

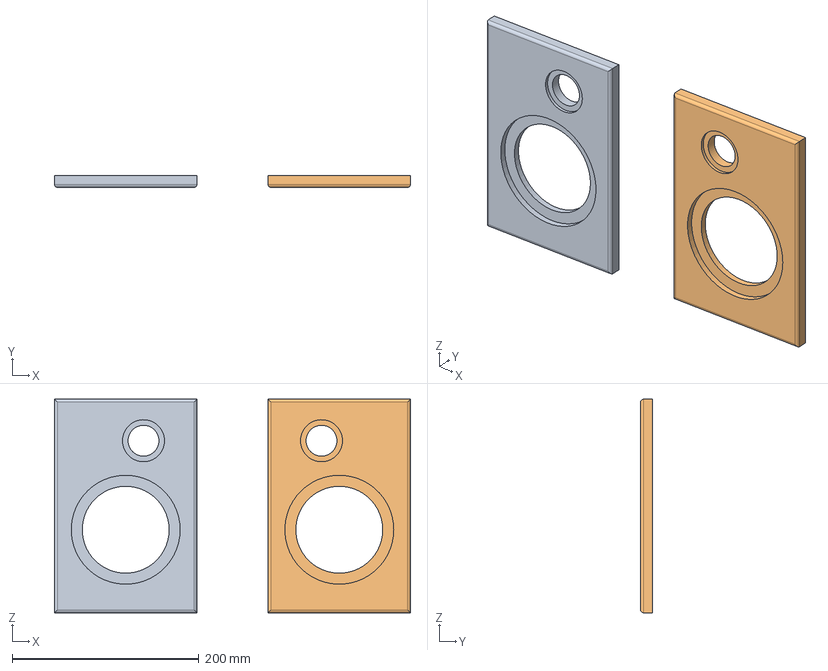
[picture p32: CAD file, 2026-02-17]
bookshelf/Overnight Sensations.FCStd
381.0 x 12.7 x 228.6 mm
Baffle Left
Baffle Right

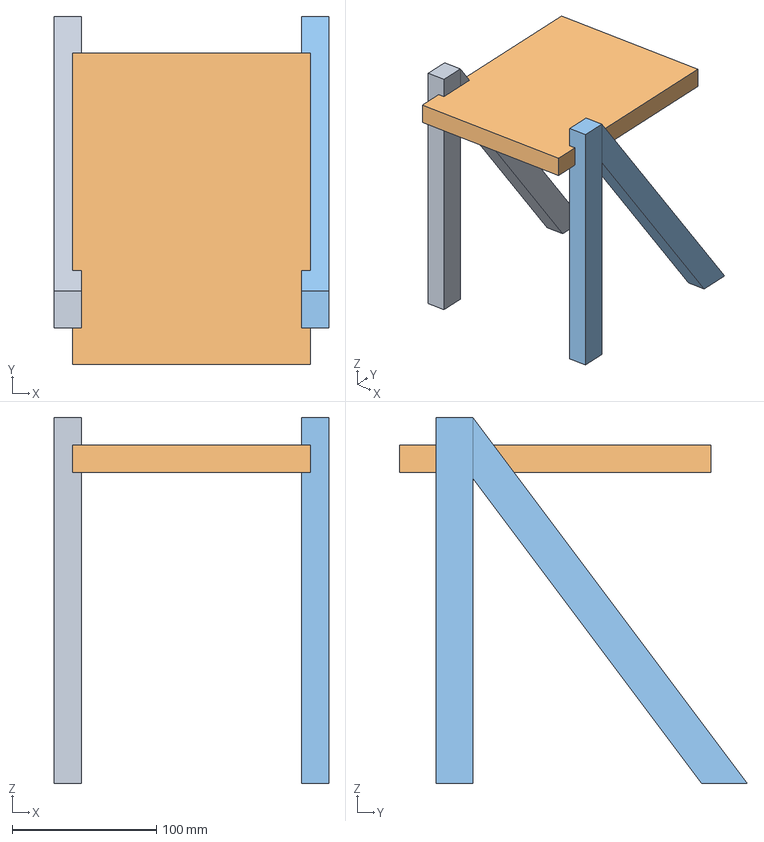
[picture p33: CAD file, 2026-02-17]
bookshelf/Stands/Stand-idea1.FCStd
190.5 x 241.3 x 254.0 mm

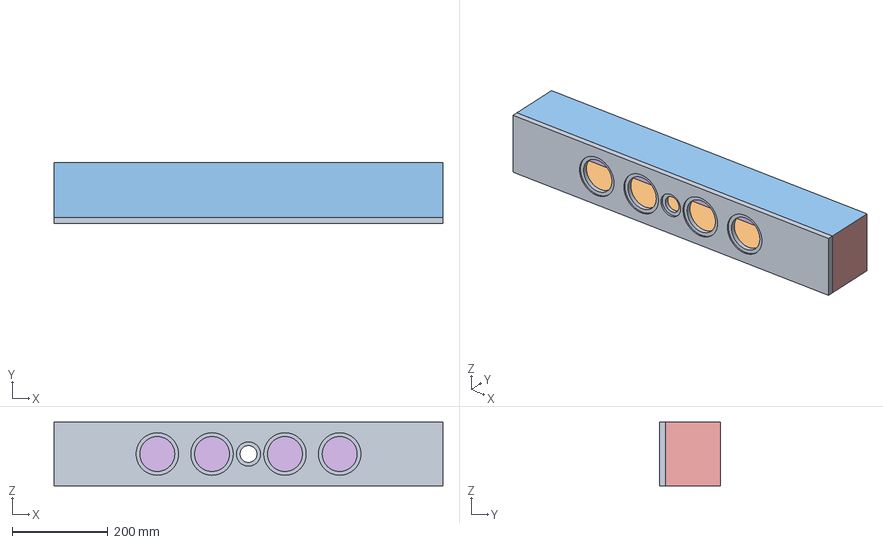
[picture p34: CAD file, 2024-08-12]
center/Overnight Sensations Center MMTMM.FCStd
812.8 x 127.0 x 133.4 mm

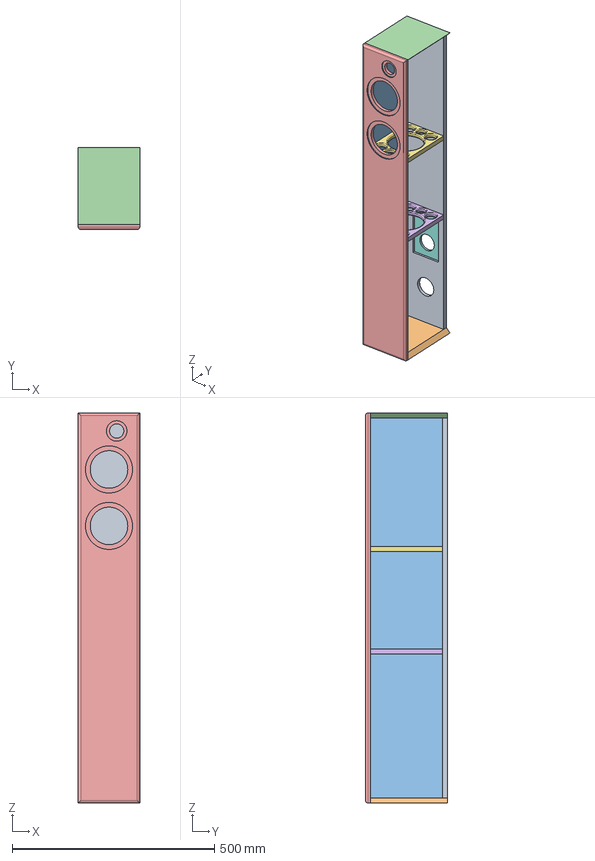
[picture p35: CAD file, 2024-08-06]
floorstanding/Overnight Sensations TMM Cabinet.FCStd
152.4 x 203.2 x 965.2 mm
window_brace001
terminal_cover

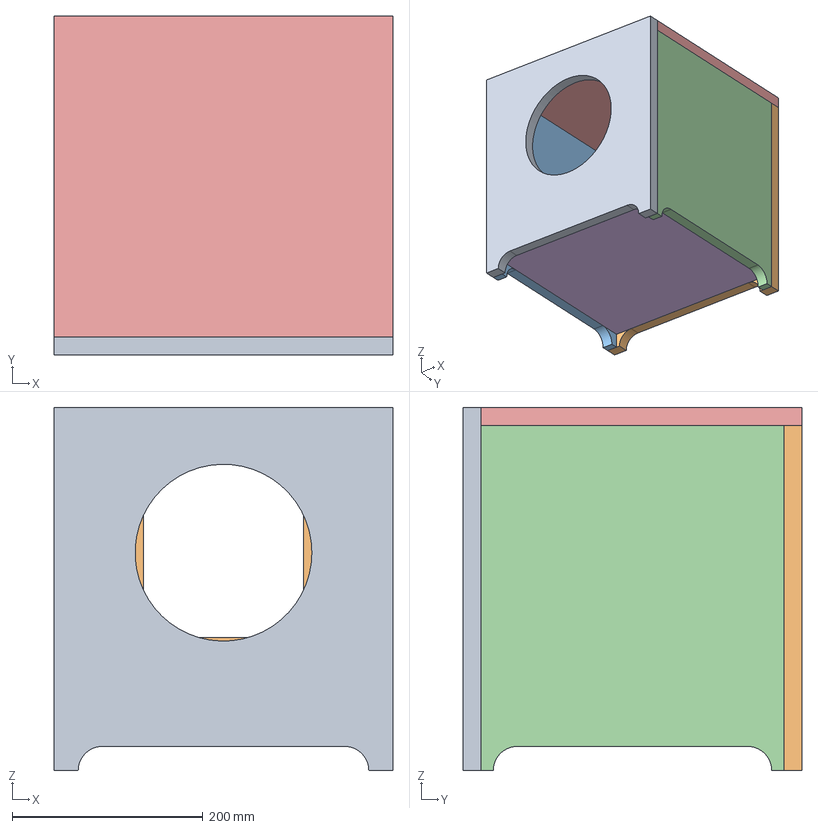
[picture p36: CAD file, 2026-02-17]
subwoofer-turtle2/Turtle 2 Subwoofer.FCStd
355.6 x 355.6 x 381.0 mm
Front
Rear
left
right
top
bottom
port-mid
port-top
port-left
port-right

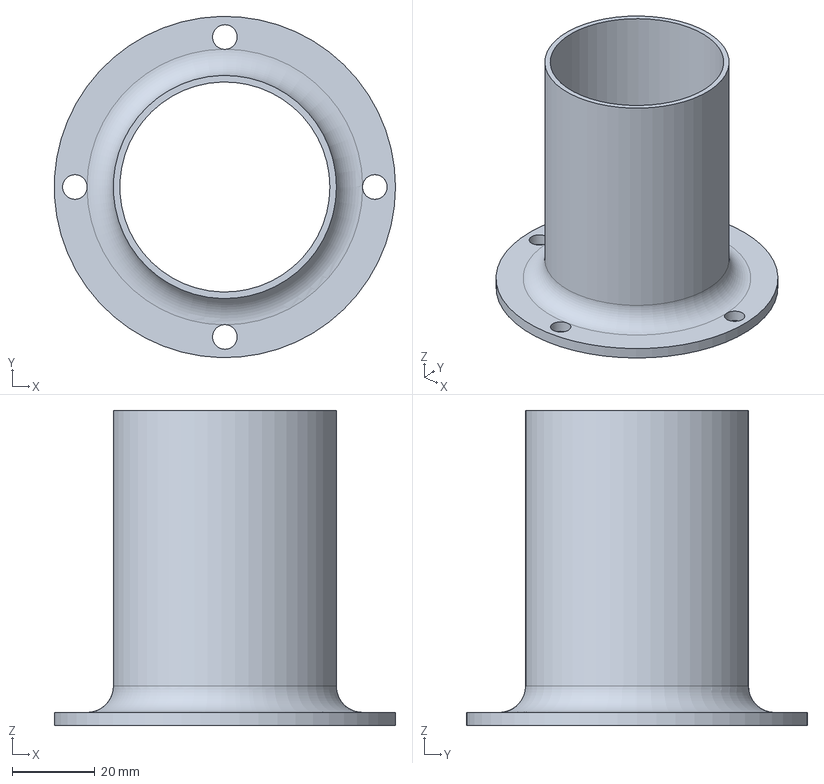
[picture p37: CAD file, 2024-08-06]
floorstanding/2x3 Speaker Port.FCStd
82.5 x 82.5 x 76.2 mm

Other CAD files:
bookshelf/Overnight-Sensations-Cabinet.skp

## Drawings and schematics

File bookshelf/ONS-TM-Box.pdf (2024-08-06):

H

G

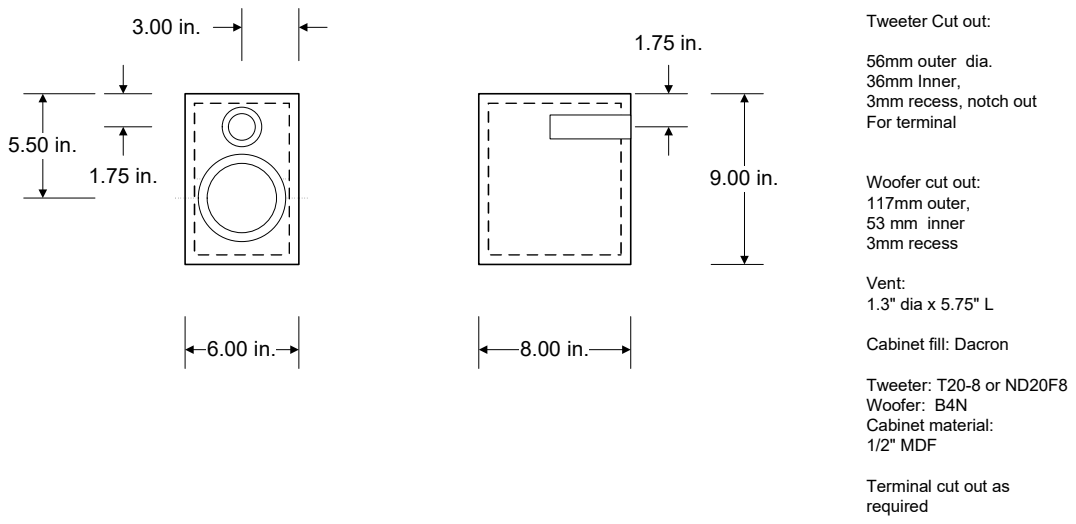
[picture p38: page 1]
REV; Overnight Sensation by Paul Carmody; APPROVED

Tweeter Cut out:
56mm outer dia.
36mm Inner,
3mm recess, notch out
For terminal

Woofer cut out:
117mm outer,
53 mm inner
3mm recess
Vent:
1.3" dia x 5.75" L
Cabinet fill: Dacron
Tweeter: T20-8 or ND20F8
Woofer: B4N
Cabinet material:
1/2" MDF
Terminal cut out as
required

Meniscus Audio Group. Inc.

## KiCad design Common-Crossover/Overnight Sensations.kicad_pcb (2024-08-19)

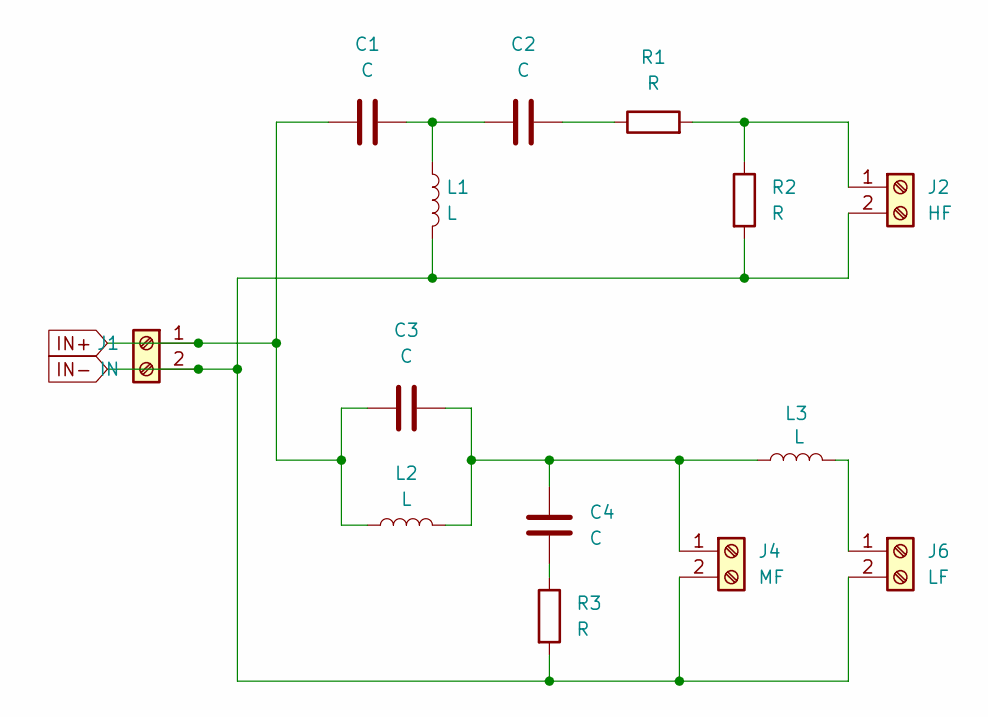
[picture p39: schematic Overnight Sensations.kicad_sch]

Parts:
C1, C2: C; C_Audio_31x14
C3: C; C_Audio_18x07
C4: C; C_Audio_45x18
J1: IN; screw_terminal_01x02_p9.5mm
J2: HF; screw_terminal_01x02_p9.5mm
J4: MF; screw_terminal_01x02_p9.5mm
J6: LF; screw_terminal_01x02_p9.5mm
L1: L; L_Audio_D40_W18_Vertical
L2: L; L_Audio_D48_W16_Horizontal
L3: L; L_Audio_61x38_Iron
R1, R2, R3: R; R_Axial_Power_L48.0mm_W12.5mm_P55.88mm

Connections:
IN+: C1.1, C3.1, J1.1, L2.1
IN-: J1.2, J2.2, J4.2, J6.2, L1.2, R2.2, R3.2
unnamed: C1.2, C2.1, L1.1
unnamed: C2.2, R1.1
unnamed: C4.2, R3.1
unnamed: J2.1, R1.2, R2.1
unnamed: C3.2, C4.1, J4.1, L2.2, L3.2
unnamed: J6.1, L3.1

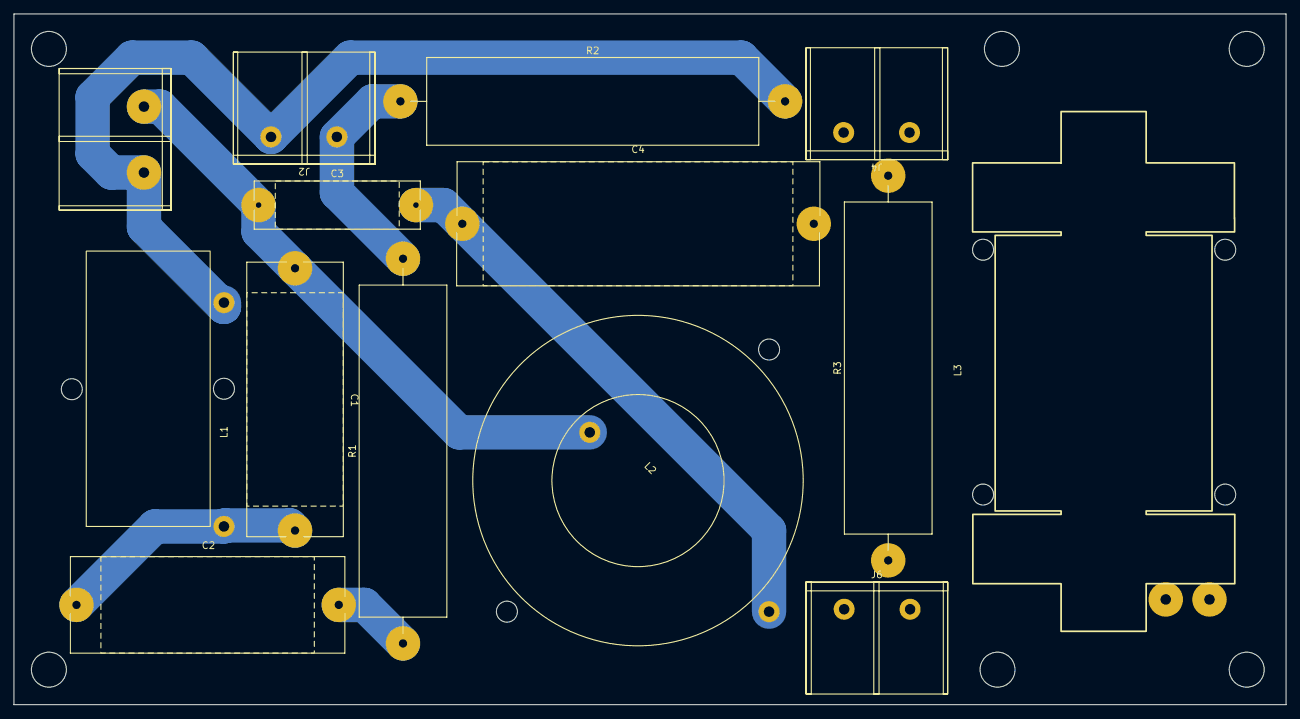
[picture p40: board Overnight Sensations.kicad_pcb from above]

Board: 2 copper layers, 184.8 x 100.3 mm, 14 parts (0 on the bottom side), 8 nets.

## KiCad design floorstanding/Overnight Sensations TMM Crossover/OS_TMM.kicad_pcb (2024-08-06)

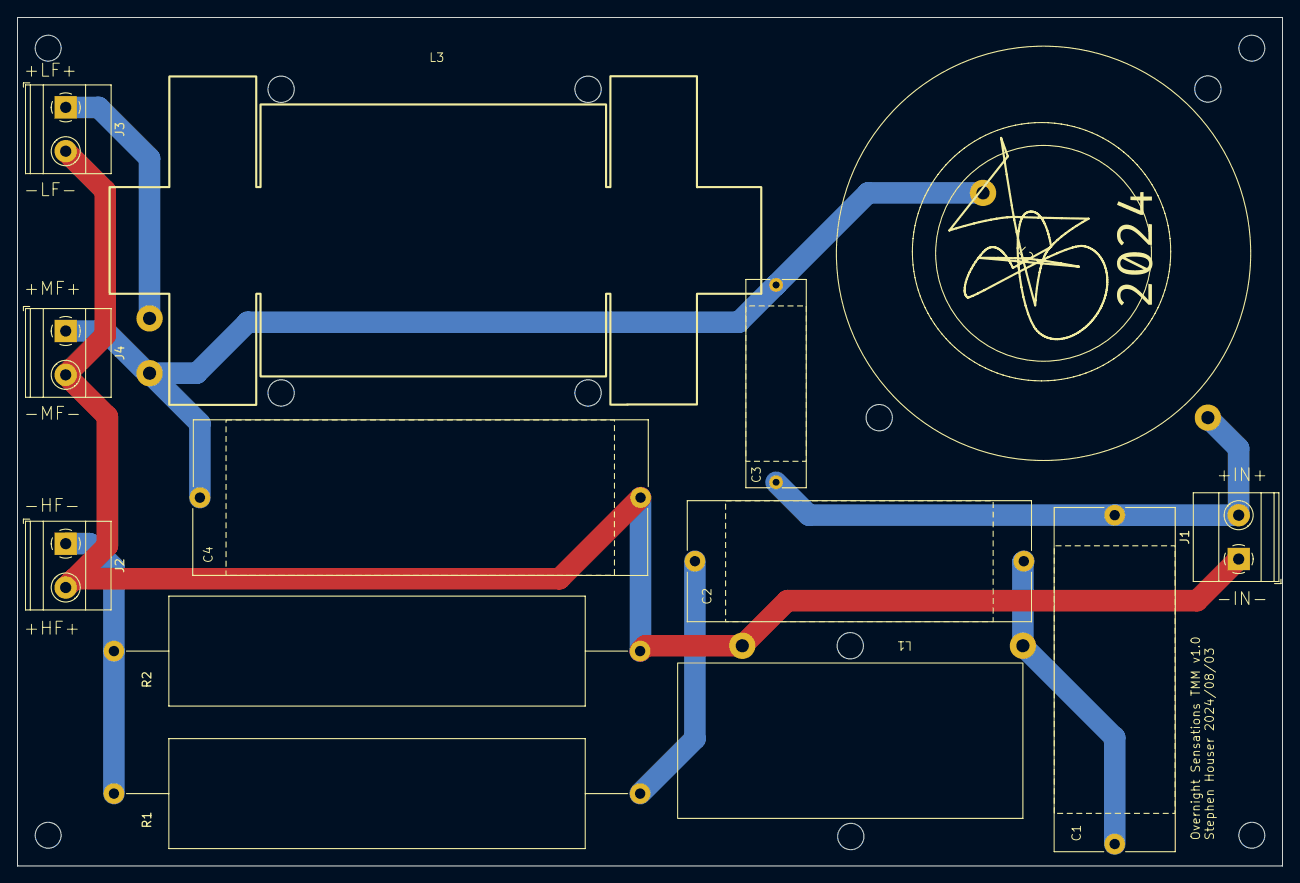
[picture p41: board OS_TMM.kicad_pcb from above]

Board: 2 copper layers, 146.6 x 98.3 mm, 13 parts (0 on the bottom side), 7 nets.

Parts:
C1: 2.2uF; C_Audio_31x14
C2: 2.7uF; C_Audio_31x14
C3: 0.22uF; C_Audio_18x07
C4: 6.8uF; C_Audio_45x18
J1: In; TerminalBlock_Phoenix_MKDS-1,5-2-5.08_1x02_P5.08mm_Horizont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
J2: High; TerminalBlock_Phoenix_MKDS-1,5-2-5.08_1x02_P5.08mm_Horizont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
J3: Low; TerminalBlock_Phoenix_MKDS-1,5-2-5.08_1x02_P5.08mm_Horizont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
J4: Mid; TerminalBlock_Phoenix_MKDS-1,5-2-5.08_1x02_P5.08mm_Horizont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
L1: 0.30mH; L_Audio_D40_W18_Vertical
L2: 1.5mH; L_Audio_D48_W16_Horizontal
L3: 3.5mH; L_Audio_61x38_Iron
R1: 5.1; R_Axial_Power_L48.0mm_W12.5mm_P60.96mm
R2: 4.7; R_Axial_Power_L48.0mm_W12.5mm_P60.96mm

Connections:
HF+: C4.2, J1.1, J2.2, J3.2, J4.2, L1.2, R2.2
HF-: J2.1, R1.1, R2.1
IN+: C1.2, C3.2, J1.2, L2.2
LOW+: J3.1, L3.1
MID+: C3.1, C4.1, J4.1, L2.1, L3.2
unnamed: C1.1, C2.2, L1.1
unnamed: C2.1, R1.2

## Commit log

2024-08-06 add center cad design
    [Overnight Sensations Center MMTMM.FCStd]
2024-08-06 add center and center drawing
    [Overnight Sensations Center MMTMM.FCStd, Overnight Sensations TMM Cabinet.FCStd]
2024-08-06 new center drawing
    [Overnight Sensations Center MMTMM.FCStd]
2024-08-12 update readme with note about corssover
    [Overnight Sensations Center MMTMM.FCStd]
2024-08-19 update readme, add common-crossover (not used)
    [Component Values.xlsx, Overnight Sensations-v2.0.kicad_pcb, Overnight Sensations-v2.1.kicad_pcb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]
2026-02-17 update, add OS freecad start
    [Floorstanding and Center Components.xlsx, Overnight Sensations.FCStd, Stand-idea1.FCStd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]
